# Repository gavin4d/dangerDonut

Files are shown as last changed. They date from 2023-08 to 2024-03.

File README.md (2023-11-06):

# Danger Donut

robot animation

Danger Donut is a work-in-progress 150 gram melty brain combat robot.

This repository contains:
* Code for the operations of the bot
* Code for the IR beacon modulation
* ESC configs
* Main board PCB design
* IR beacon PCB design
* POV display artwork

Links:
* [Bill of Materials](https://docs.google.com/spreadsheets/d/1dkWNEsBBoqDzMkqIhuPgsKdvJ411szMJZwjo1TRifCI/edit?usp=sharing)
* [Full Robot CAD](https://cad.onshape.com/documents/b2161876893824b000416544/w/ad922c252fa114c5bccae0f6/e/2d73a76351a9b656583123fa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)
* [IR Beacon CAD for Xbox controller](https://cad.onshape.com/documents/fe686b6ebfe56c60cbf11a52/w/a5235571450e0940f943c7f9/e/e1fc86eb24f972fd453b77be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)
* [Transport Box CAD](https://cad.onshape.com/documents/9698310442d8aade0d12c8ac/w/1dfdf825a6ce81e21ee8f0cf/e/f9df83b772e96680fdb5acf9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)

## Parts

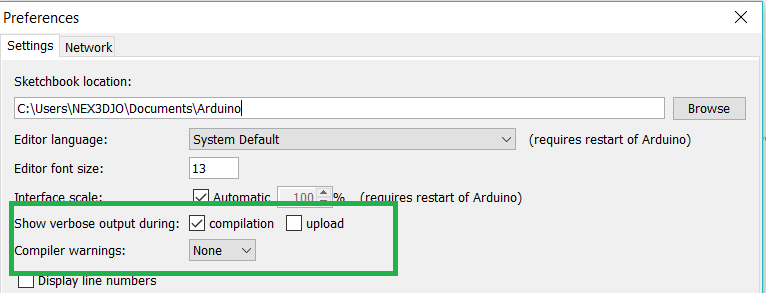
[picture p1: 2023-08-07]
components/arduino/docs/source/_static/ota_esp32_verbose.png

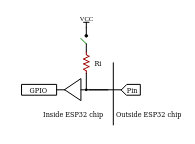
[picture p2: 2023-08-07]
components/arduino/docs/source/_static/gpio_pullup.png

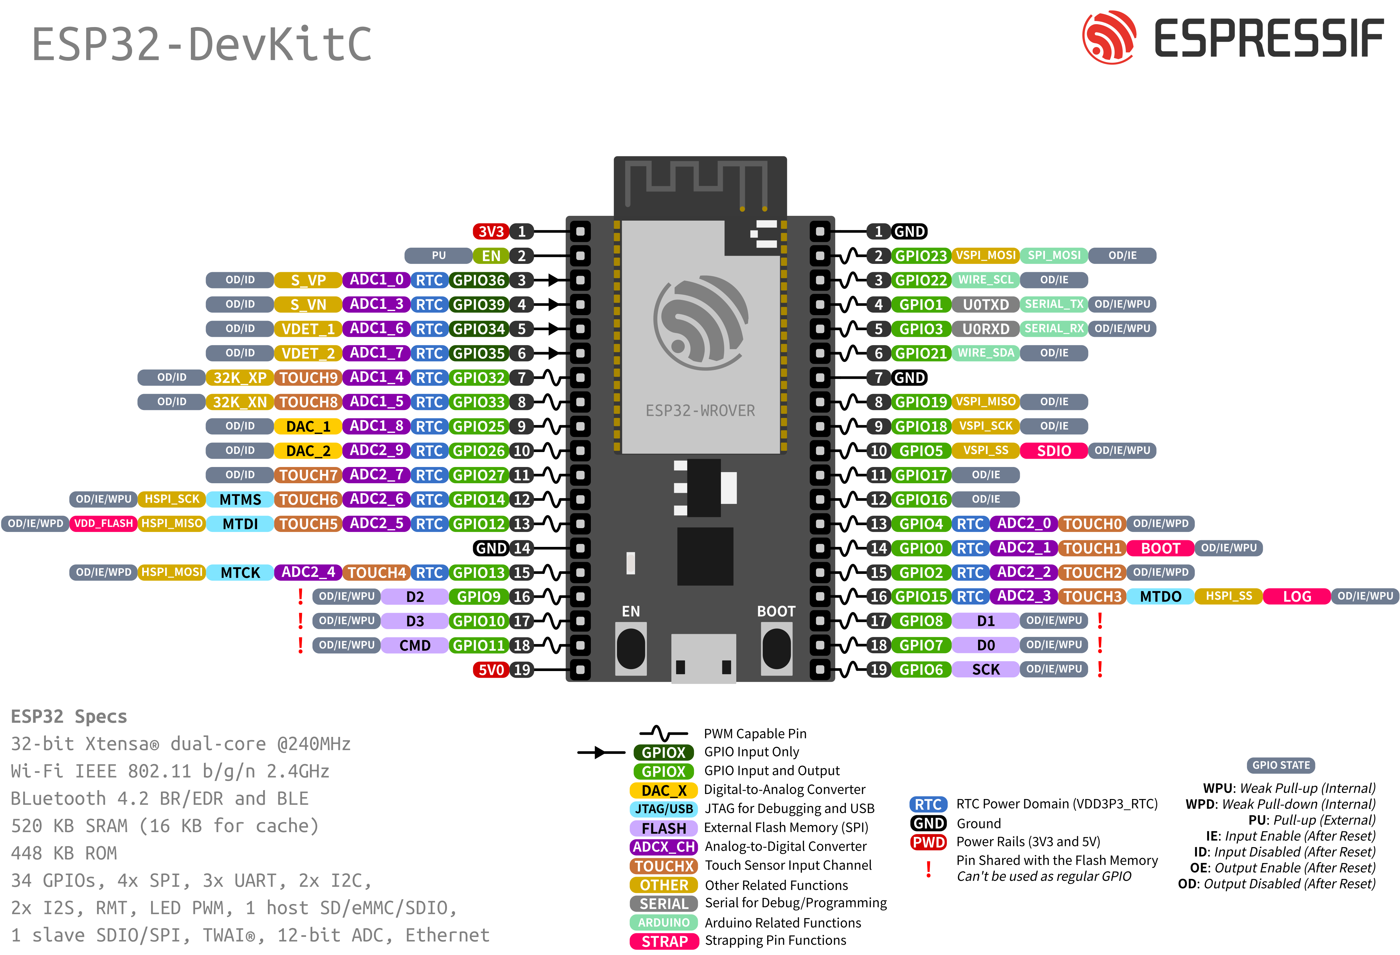
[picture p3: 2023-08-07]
components/arduino/docs/source/_static/esp32_devkitC_pinlayout.png

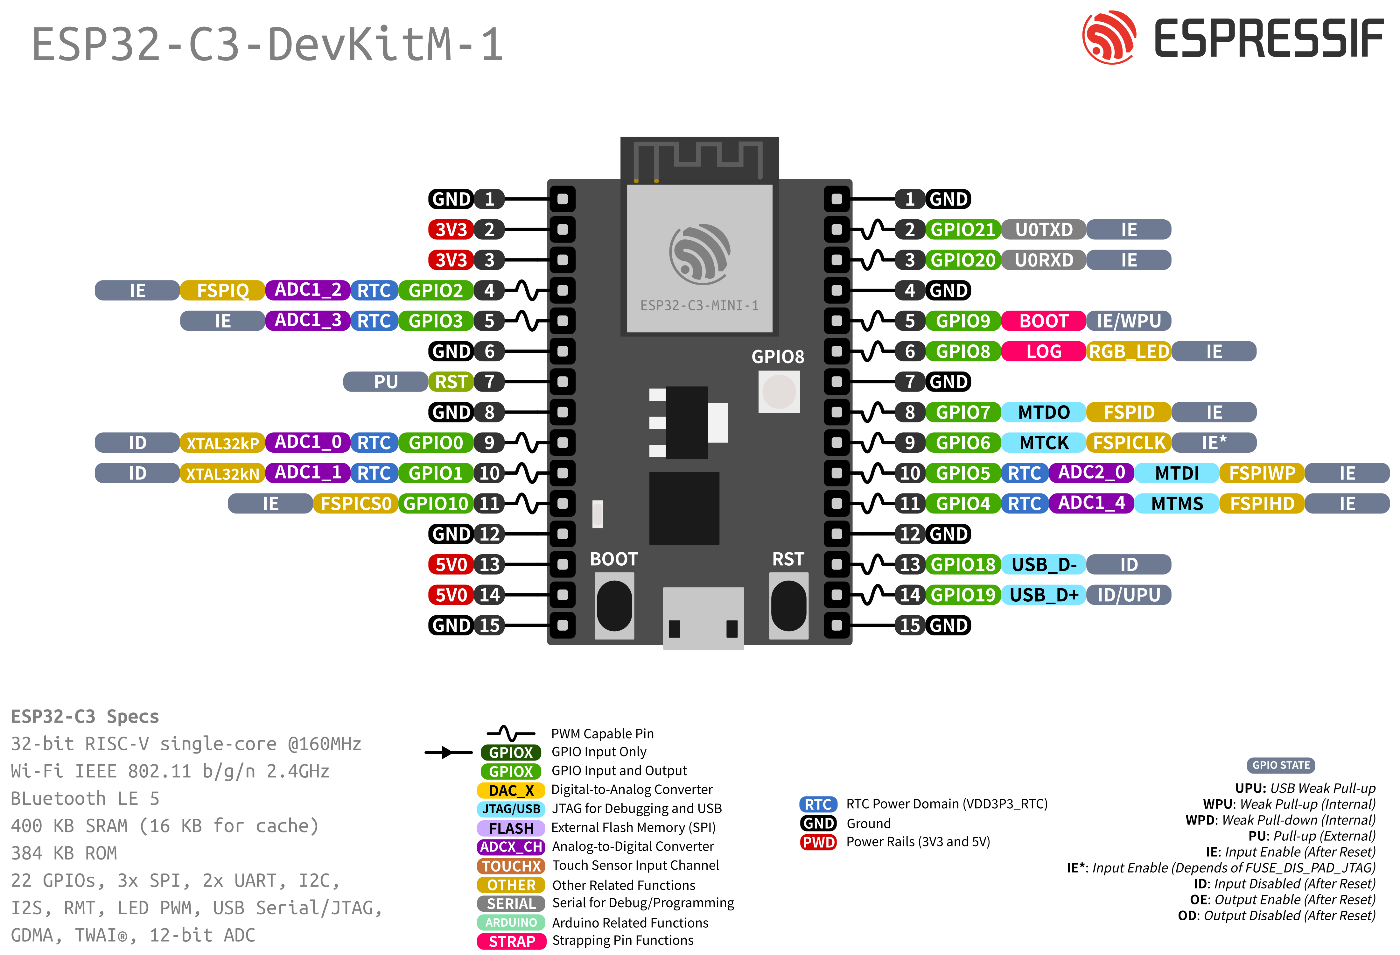
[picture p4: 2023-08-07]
components/arduino/docs/source/_static/esp32-c3_devkitM-1_pinlayout.png

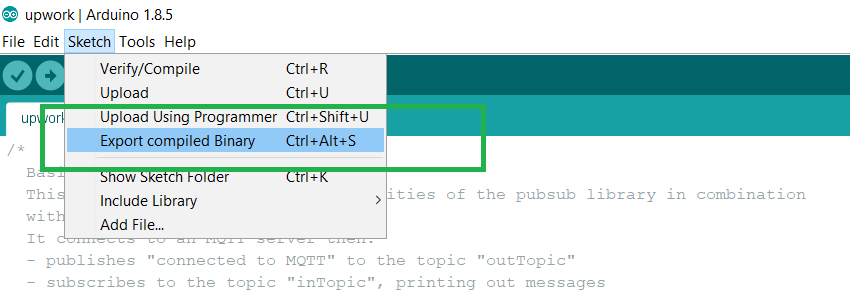
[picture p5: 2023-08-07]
components/arduino/docs/source/_static/ota_export_to_binary.png

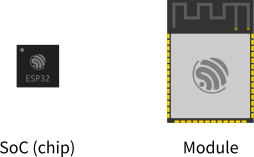
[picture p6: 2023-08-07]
components/arduino/docs/source/_static/soc-module.png

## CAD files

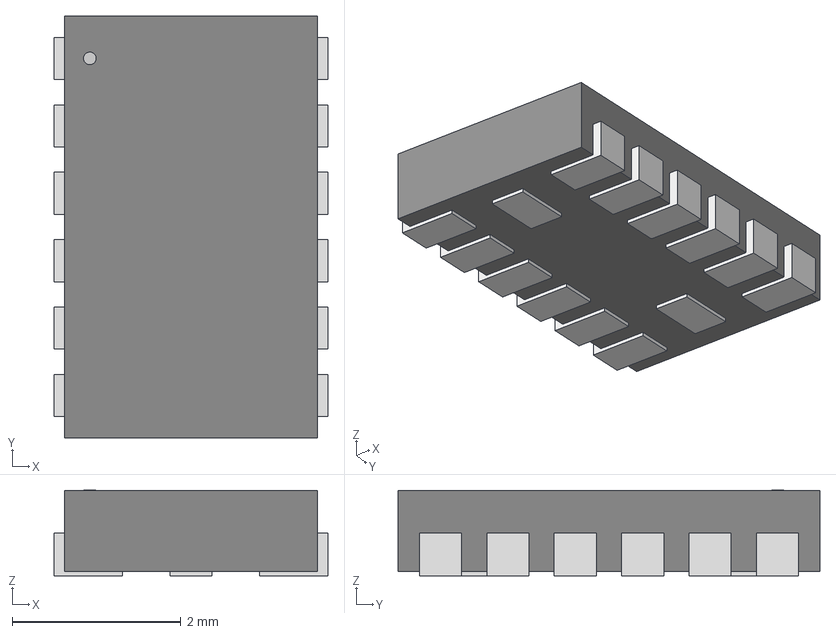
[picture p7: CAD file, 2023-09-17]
PCB/MainBoard/partFiles/step/LGA_CC-14-1_ADI.step
3.25 x 5.00 x 1.02 mm

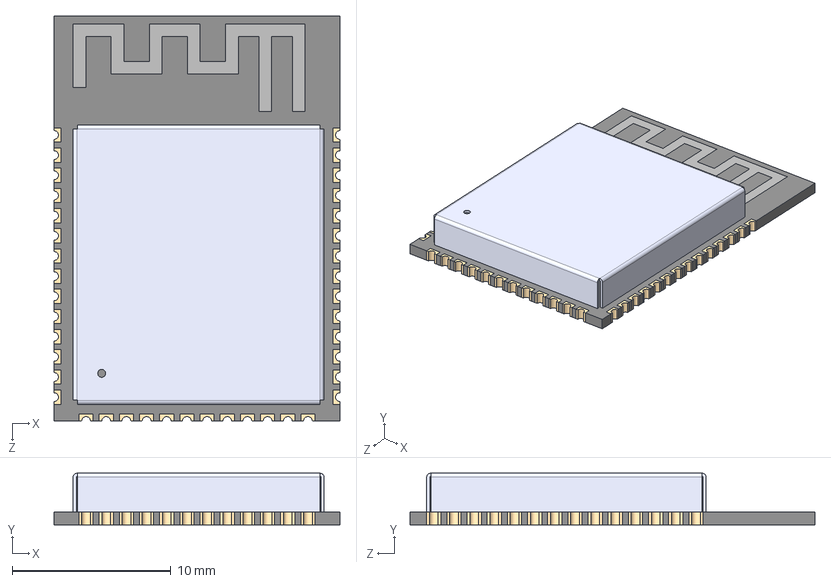
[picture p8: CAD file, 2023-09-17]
PCB/MainBoard/partFiles/step/ESP32-S3-WROOM-1-N8R2.step
18.0 x 3.25 x 25.5 mm

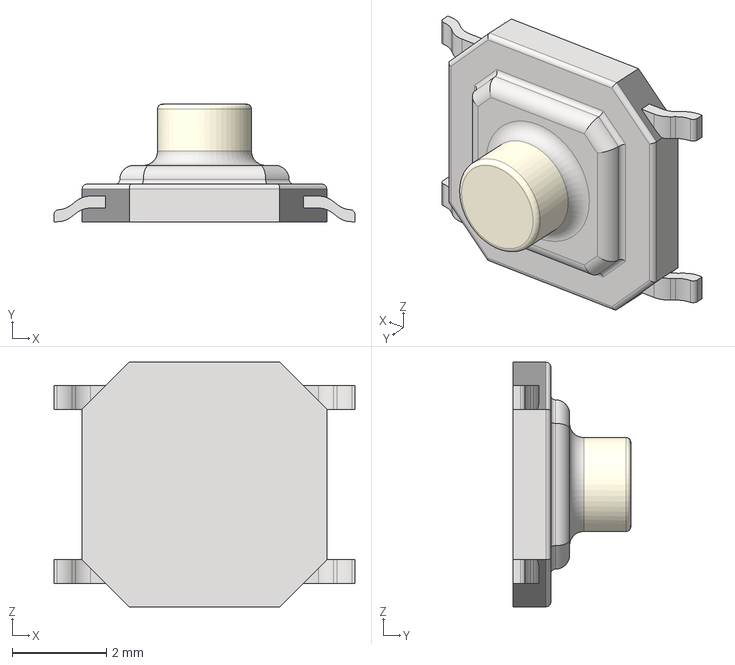
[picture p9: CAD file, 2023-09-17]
PCB/MainBoard/partFiles/step/tact_switch_2.5mm.step
6.40 x 2.50 x 5.20 mm

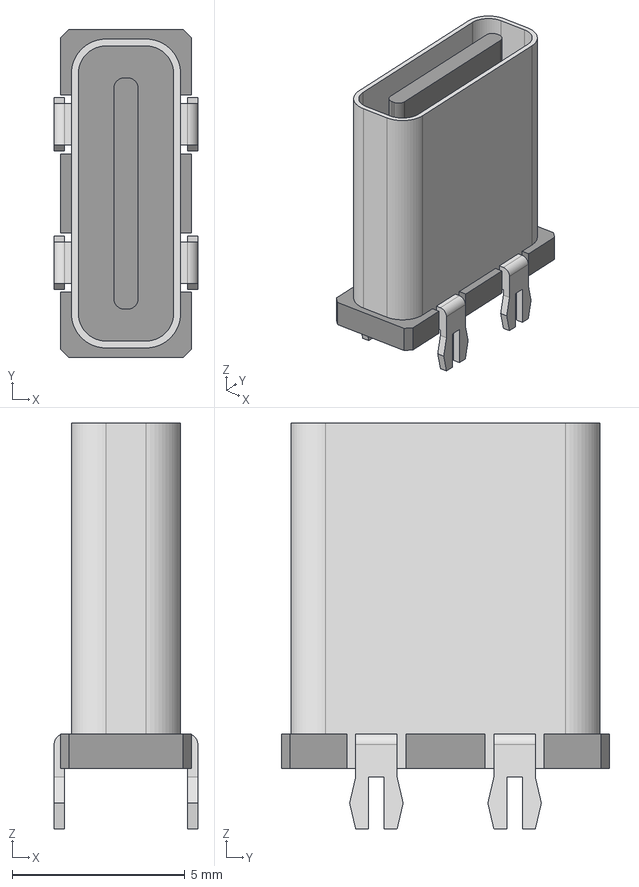
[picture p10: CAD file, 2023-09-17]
PCB/MainBoard/partFiles/step/TYPE-C_16PLC-H10.0.step
4.16 x 9.50 x 11.8 mm

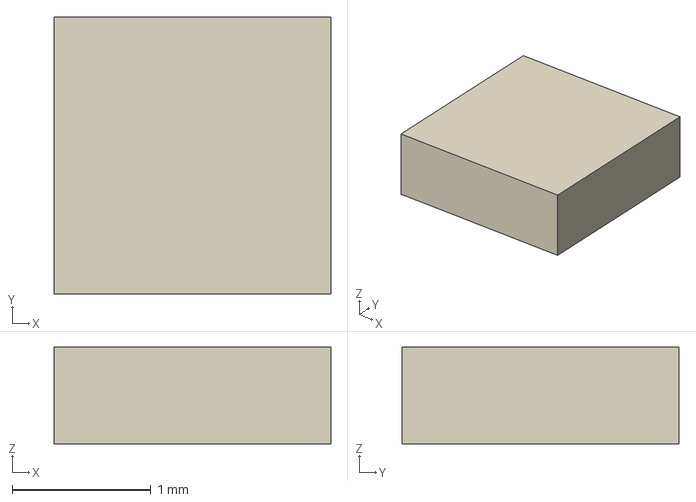
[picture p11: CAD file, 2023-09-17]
PCB/MainBoard/partFiles/step/HD107S_CAD.step
2.00 x 2.00 x 0.7 mm

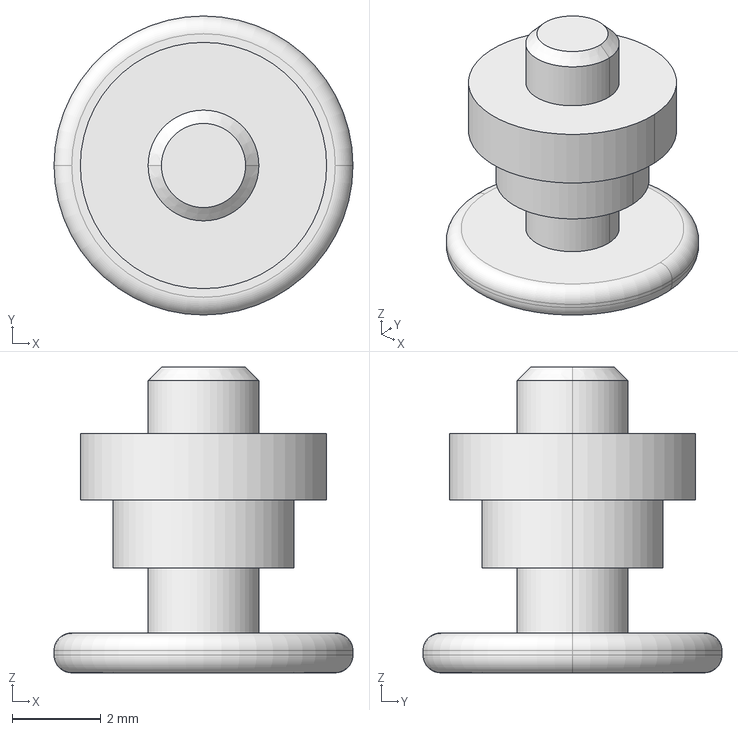
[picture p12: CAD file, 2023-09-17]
PCB/MainBoard/partFiles/step/hex bolt switch.step
6.75 x 6.75 x 6.90 mm

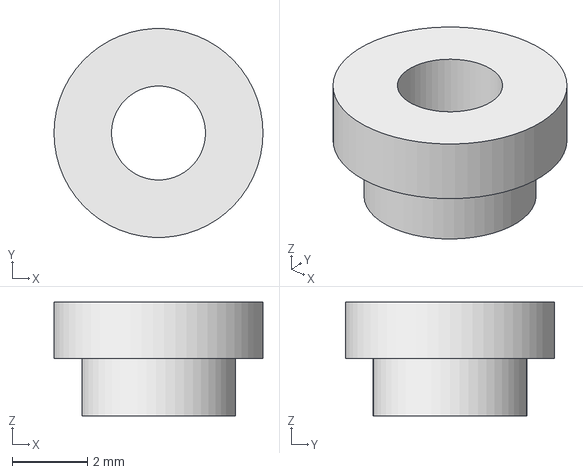
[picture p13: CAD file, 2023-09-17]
PCB/MainBoard/partFiles/step/smd nut.step
5.56 x 5.55 x 3.03 mm

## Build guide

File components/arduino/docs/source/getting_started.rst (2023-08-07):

###############
Getting Started
###############

About Arduino ESP32
-------------------

Welcome to the Arduino ESP32 support documentation! Here you will find important information on how to use the project.

First Things First
------------------

.. note::
    Before continuing, we must be clear that this project is supported by `Espressif Systems`_ and the community.
    Everyone is more than welcome to contribute back to this project.

ESP32 is a single 2.4 GHz Wi-Fi-and-Bluetooth SoC (System On a Chip) designed by `Espressif Systems`_.

ESP32 is designed for mobile, wearable electronics, and Internet-of-Things (IoT) applications. It features all the state-of-the-art characteristics 
of low-power chips, including fine-grained clock gating, multiple power modes,and dynamic power scaling. For instance, in a low-power IoT sensor 
hub application scenario, ESP32 is woken-up periodically and only when a specified condition is detected. Low-duty cycle is used to minimize the 
amount of energy that the chip expends. 

The output of the power amplifier is also adjustable, thus contributing to an optimal trade-off between communication range, data rate and 
power consumption.

The ESP32 series is available as a chip or module.

.. _supported_socs:

Supported SoC's
---------------

Here are the ESP32 series supported by the Arduino-ESP32 project:

======== ====== =========== ===================================
SoC      Stable Development Datasheet
======== ====== =========== ===================================
ESP32    Yes    Yes         `ESP32`_
ESP32-S2 Yes    Yes         `ESP32-S2`_
ESP32-C3 Yes    Yes         `ESP32-C3`_
ESP32-S3 Yes    Yes         `ESP32-S3`_
======== ====== =========== ===================================

See `Boards <boards/boards.html>`_ for more details about ESP32 development boards.

Arduino Core Reference
----------------------

This documentation is built on the ESP32 and we are not going to cover the common Arduino API. To see the Arduino reference documentation, 
please consider reading the official documentation.

Arduino Official Documentation: `Arduino Reference`_.

Supported Operating Systems
---------------------------

+-------------------+-------------------+-------------------+
|     |       |       |
+-------------------+-------------------+-------------------+
| Windows           | Linux             | macOS             |
+-------------------+-------------------+-------------------+





Supported IDEs
---------------------------

Here is the list of supported IDE for Arduino ESP32 support integration.

+-------------------+-------------------+
|     |         |
+-------------------+-------------------+
| Arduino IDE       | PlatformIO        |
+-------------------+-------------------+




See `Installing Guides <installing.html>`_ for more details on how to install the Arduino ESP32 support.

Support
-------

This is an open project and it's supported by the community. Fell free to ask for help in one of the community channels.

Community
---------

The Arduino community is huge! You can find a lot of useful content on the Internet.
Here are some community channels where you may find information and ask for some help, if needed.

- `ESP32 Forum`_: Official Espressif Forum.
- `ESP32 Forum - Arduino`_: Official Espressif Forum for Arduino related discussions.
- `ESP32 Forum - Hardware`_: Official Espressif Forum for Hardware related discussions.
- `Gitter`_
- `Espressif MCUs (Discord)`_
- `ESP32 on Reddit`_

Issues Reporting
----------------

Before opening a new issue, please read this: 

Be sure to search for a similar reported issue. This avoids duplicating or creating noise in the GitHub Issues reporting.
We also have the troubleshooting guide to save your time on the most common issues reported by users.

For more details about creating new Issue, see the `Issue Template <https://github.com/espressif/arduino-esp32/blob/master/.github/ISSUE_TEMPLATE/Issue-report.yml>`_.

If you have any new idea, see the `Feature request Template <https://github.com/espressif/arduino-esp32/blob/master/.github/ISSUE_TEMPLATE/Feature-request.yml>`_.

First Steps
-----------

Here are the first steps to get the Arduino ESP32 support running.

To install Arduino-ESP32, please see the dedicated section on the Installation guide. We recommend you install it using the boards manager.

.. toctree::
    :maxdepth: 2
    
    How to Install <installing>
    Development Boards <boards/boards>

Examples
--------

After installing the toolchain into your environment, you will be able to see all the dedicated examples for the ESP32. These examples are located
in the examples menu or inside each library folder.

    https://github.com/espressif/arduino-esp32/tree/master/libraries

There is also a `list of examples <https://techtutorialsx.com/category/esp32/>`_ managed outside of Espressif, so check them out.

.. include:: common/datasheet.inc

Resources
---------

.. _Espressif Systems: https://www.espressif.com 
.. _Espressif Product Selector: https://products.espressif.com/
.. _Arduino.cc: https://www.arduino.cc/en/Main/Software
.. _Arduino Reference: https://www.arduino.cc/reference/en/
.. _ESP32 Forum: https://esp32.com
.. _ESP32 Forum - Arduino: https://esp32.com/viewforum.php?f=19
.. _ESP32 Forum - Hardware: https://esp32.com/viewforum.php?f=12
.. _Gitter: https://gitter.im/espressif/arduino-esp32
.. _Adafruit (Discord): https://discord.gg/adafruit
.. _Espressif MCUs (Discord): https://discord.gg/nKxMTnkD
.. _ESP32 on Reddit: https://www.reddit.com/r/esp32

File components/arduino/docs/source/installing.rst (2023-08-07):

##########
Installing
##########

This guide will show how to install the Arduino-ESP32 support.

Before Installing
-----------------

We recommend you install the support using your favorite IDE, but other options are available depending on your operating system. 
To install Arduino-ESP32 support, you can use one of the following options.

Installing using Arduino IDE
----------------------------



This is the way to install Arduino-ESP32 directly from the Arduino IDE.

.. note::
   For overview of SoC's support, take a look on `Supported Soc's table <https://docs.espressif.com/projects/arduino-esp32/en/latest/getting_started.html#supported-soc-s>`_ where you can find if the particular chip is under stable or development release.

- Stable release link::

   https://espressif.github.io/arduino-esp32/package_esp32_index.json

- Development release link::

   https://espressif.github.io/arduino-esp32/package_esp32_dev_index.json

.. note::
   Starting with the Arduino IDE version 1.6.4, Arduino allows installation of third-party platform 
   packages using Boards Manager. We have packages available for Windows, macOS, and Linux.

To start the installation process using the Boards Managaer, follow these steps:

-  Install the current upstream Arduino IDE at the 1.8 level or later. The current version is at the `arduino.cc`_ website.

-  Start Arduino and open the Preferences window.



-  Enter one of the release links above into *Additional Board Manager URLs* field. You can add multiple URLs, separating them with commas.



-  Open Boards Manager from Tools > Board menu and install *esp32* platform (and do not forget to select your ESP32 board from Tools > Board menu after installation).



- Restart Arduino IDE.

Installing using PlatformIO
---------------------------



PlatformIO is a professional collaborative platform for embedded development. It has out-of-the-box support for ESP32 SoCs and allows working with Arduino ESP32 as well as ESP-IDF from Espressif without changing your development environment. PlatformIO includes lots of instruments for the most common development tasks such as debugging, unit testing, and static code analysis.

A detailed overview of the PlatformIO ecosystem and its philosophy can be found in `the official documentation <https://docs.platformio.org/en/latest/core/index.html>`_.

PlatformIO can be used in two flavors:

- `PlatformIO IDE <https://platformio.org/platformio-ide>`_ is a toolset for embedded C/C++ development available on Windows, macOS and Linux platforms

- `PlatformIO Core (CLI) <https://docs.platformio.org/en/latest/core/index.html>`_ is a command-line tool that consists of a multi-platform build system, platform and library managers and other integration components. It can be used with a variety of code development environments and allows integration with cloud platforms and web services

To install PlatformIO, you can follow this Getting Started, provided at `docs.platformio.org`_.

Using the stable code
*********************

.. note::
   A detailed overview of supported development boards, examples and frameworks can be found on `the official Espressif32 dev-platform page <https://registry.platformio.org/platforms/platformio/espressif32>`_ in the PlatformIO Registry.

The most reliable and easiest way to get started is to use the latest stable version of the ESP32 development platform that passed all tests/verifications and can be used in production.

Create a new project and select one of the available boards. You can change after by changing the `platformio.ini <https://docs.platformio.org/en/latest/projectconf/index.html>`_ file.

- For ESP32

.. code-block:: bash

   [env:esp32dev]
   platform = espressif32
   board = esp32dev
   framework = arduino

- For ESP32-S2 (ESP32-S2-Saola-1 board)

.. code-block:: bash

   [env:esp32-s2-saola-1]
   platform = espressif32
   board = esp32-s2-saola-1
   framework = arduino

- For ESP32-C3 (ESP32-C3-DevKitM-1 board)

.. code-block:: bash

   [env:esp32-c3-devkitm-1]
   platform = espressif32
   board = esp32-c3-devkitm-1
   framework = arduino

How to update to the latest code
********************************

To test the latest Arduino ESP32, you need to change your project *platformio.ini* accordingly.
The following configuration uses the upstream version of the Espressif development platform and the latest Arduino core directly from the Espressif GitHub repository:

.. code-block:: bash

   [env:esp32-c3-devkitm-1]
   platform = https://github.com/platformio/platform-espressif32.git
   board = esp32-c3-devkitm-1
   framework = arduino
   platform_packages =
       framework-arduinoespressif32 @ https://github.com/espressif/arduino-esp32#master

To get more information about PlatformIO, see the following links:

- `PlatformIO Core (CLI) <https://docs.platformio.org/en/latest/core/index.html>`_

- `PlatformIO Home <https://docs.platformio.org/en/latest/home/index.html>`_

- `Tutorials and Examples <https://docs.platformio.org/en/latest/tutorials/index.html>`_

- `Library Management <https://docs.platformio.org/en/latest/librarymanager/index.html>`_

Windows (manual installation)
-----------------------------

.. warning:: Arduino ESP32 core v2.x.x cannot be used on Windows 8.x x86 (32 bits), Windows 7 or earlier. The Windows 32 bits OS is no longer supported by this toolchain.

   The Arduino ESP32 v1.0.6 still works on WIN32. You might want to install python 3.8.x because it is the latest release supported by Windows 7.

Steps to install Arduino ESP32 support on Windows:

**Step 1**

1. Download and install the latest Arduino IDE ``Windows Installer`` from [arduino.cc](https://www.arduino.cc/en/Main/Software)
2. Download and install Git from [git-scm.com](https://git-scm.com/download/win)
3. Start ``Git GUI`` and do the following steps:

- Select ``Clone Existing Repository``



- Select source and destination
   - Sketchbook Directory: Usually ``C:/Users/[YOUR_USER_NAME]/Documents/Arduino`` and is listed underneath the "Sketchbook location" in Arduino preferences.
   - Source Location: ``https://github.com/espressif/arduino-esp32.git``
   - Target Directory: ``[ARDUINO_SKETCHBOOK_DIR]/hardware/espressif/esp32``
   - Click ``Clone`` to start cloning the repository

**Step 2**



**Step 3**



- open a `Git Bash` session pointing to ``[ARDUINO_SKETCHBOOK_DIR]/hardware/espressif/esp32`` and execute ```git submodule update --init --recursive``` 
- Open ``[ARDUINO_SKETCHBOOK_DIR]/hardware/espressif/esp32/tools`` and double-click ``get.exe``

**Step 4**



- When ```get.exe``` finishes, you should see the following files in the directory

**Step 5**



1. Plug your ESP32 board and wait for the drivers to install (or install manually any that might be required)
2. Start Arduino IDE
3. Select your board in ``Tools > Board`` menu
4. Select the COM port that the board is attached to
5. Compile and upload (You might need to hold the boot button while uploading)



How to update to the latest code
********************************

1. Start ``Git GUI`` and you should see the repository under ``Open Recent Repository``. Click on it!



1. From menu ``Remote`` select ``Fetch from`` > ``origin``



1. Wait for git to pull any changes and close ``Git GUI``
2. Open ``[ARDUINO_SKETCHBOOK_DIR]/hardware/espressif/esp32/tools`` and double-click ``get.exe``



Linux
-----



Debian/Ubuntu
*************

- Install latest Arduino IDE from `arduino.cc`_.

- Open Terminal and execute the following command (copy -> paste and hit enter):

.. code-block:: bash

   sudo usermod -a -G dialout $USER && \
   sudo apt-get install git && \
   wget https://bootstrap.pypa.io/get-pip.py && \
   sudo python3 get-pip.py && \
   sudo pip3 install pyserial && \
   mkdir -p ~/Arduino/hardware/espressif && \
   cd ~/Arduino/hardware/espressif && \
   git clone https://github.com/espressif/arduino-esp32.git esp32 && \
   cd esp32/tools && \
   python3 get.py

- Restart Arduino IDE.

- If you have Arduino installed to ~/, modify the installation as follows, beginning at `mkdir -p ~/Arduino/hardware`:

.. code-block:: bash

   cd ~/Arduino/hardware
   mkdir -p espressif && \
   cd espressif && \
   git clone https://github.com/espressif/arduino-esp32.git esp32 && \
   cd esp32/tools && \
   python3 get.py

Fedora
******

- Install the latest Arduino IDE from `arduino.cc`_.

.. note::
   Command ``$ sudo dnf -y install arduino`` will most likely install an older release.

- Open Terminal and execute the following command (copy -> paste and hit enter):

.. code-block:: bash

   sudo usermod -a -G dialout $USER && \
   sudo dnf install git python3-pip python3-pyserial && \
   mkdir -p ~/Arduino/hardware/espressif && \
   cd ~/Arduino/hardware/espressif && \
   git clone https://github.com/espressif/arduino-esp32.git esp32 && \
   cd esp32/tools && \
   python get.py

- Restart Arduino IDE.

openSUSE
********

- Install the latest Arduino IDE from `arduino.cc`_.

- Open Terminal and execute the following command (copy -> paste and hit enter):

.. code-block:: bash

   sudo usermod -a -G dialout $USER && \
   if [ `python --version 2>&1 | grep '2.7' | wc -l` = "1" ]; then \
   sudo zypper install git python-pip python-pyserial; \
   else \
   sudo zypper install git python3-pip python3-pyserial; \
   fi && \
   mkdir -p ~/Arduino/hardware/espressif && \
   cd ~/Arduino/hardware/espressif && \
   git clone https://github.com/espressif/arduino-esp32.git esp32 && \
   cd esp32/tools && \
   python get.py

- Restart Arduino IDE.

macOS
-----

- Install the latest Arduino IDE from `arduino.cc`_.

- Open Terminal and execute the following command (copy -> paste and hit enter):

.. code-block:: bash

   mkdir -p ~/Documents/Arduino/hardware/espressif && \
   cd ~/Documents/Arduino/hardware/espressif && \
   git clone https://github.com/espressif/arduino-esp32.git esp32 && \
   cd esp32/tools && \
   python get.py 

Where ``~/Documents/Arduino`` represents your sketch book location as per "Arduino" > "Preferences" > "Sketchbook location" (in the IDE once started). Adjust the command above accordingly.

- If you get the error below, install through the command line dev tools with `xcode-select --install` and try the command above again:

.. code-block:: bash

   xcrun: error: invalid active developer path (/Library/Developer/CommandLineTools), missing xcrun at: /Library/Developer/CommandLineTools/usr/bin/xcrun

- Run the command:

.. code-block:: bash

   xcode-select --install

- Try ``python3`` instead of ``python`` if you get the error: ``IOError: [Errno socket error] [SSL: TLSV1_ALERT_PROTOCOL_VERSION] tlsv1 alert protocol version (_ssl.c:590)`` when running ``python get.py``

- If you get the following error when running ``python get.py`` urllib.error.URLError: <urlopen error SSL: CERTIFICATE_VERIFY_FAILED, go to Macintosh HD > Applications > Python3.6 folder (or any other python version), and run the following scripts: Install Certificates.command and Update Shell Profile.command

- Restart Arduino IDE.

.. _Arduino.cc: https://www.arduino.cc/en/Main/Software
.. _docs.platformio.org: https://docs.platformio.org/en/latest/integration/ide/pioide.html

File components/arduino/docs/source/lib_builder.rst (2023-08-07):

###############
Library Builder
###############

About
-----

Espressif provides a `tool <https://github.com/espressif/esp32-arduino-lib-builder>`_ to simplify building your own compiled libraries for use in Arduino IDE (or your favorite IDE).

This tool can be used to change the project or a specific configuration according to your needs.

Installing
----------

To install the Library Builder into your environment, please, follow the instructions below.

- Clone the ESP32 Arduino lib builder:

.. code-block:: bash

    git clone https://github.com/espressif/esp32-arduino-lib-builder

- Go to the ``esp32-arduino-lib-builder`` folder:

.. code-block:: bash

    cd esp32-arduino-lib-builder

- Build:

.. code-block:: bash

    ./build.sh

If everything works, you may see the following message: ``Successfully created esp32 image.``

Dependencies
************

To build the library you will need to install some dependencies. Maybe you already have installed it, but it is a good idea to check before building.

- Install all dependencies (**Ubuntu**):

.. code-block:: bash

    sudo apt-get install git wget curl libssl-dev libncurses-dev flex bison gperf cmake ninja-build ccache jq

- Install Python and upgrade pip:

.. code-block:: bash

    sudo apt-get install python3
    sudo pip install --upgrade pip

- Install all required packages:

.. code-block:: bash

    pip install --user setuptools pyserial click cryptography future pyparsing pyelftools

Building
--------

If you have all the dependencies met, it is time to build the libraries.

To build using the default configuration:

.. code-block:: bash

    ./build.sh

Custom Build
************

There are some options to help you create custom libraries. You can use the following options:

Usage
^^^^^

.. code-block:: bash

    build.sh [-s] [-A arduino_branch] [-I idf_branch] [-i idf_commit] [-c path] [-t <target>] [-b <build|menuconfig|idf_libs|copy_bootloader|mem_variant>] [config ...]

Skip Install/Update
^^^^^^^^^^^^^^^^^^^

Skip installing/updating of ESP-IDF and all components

.. code-block:: bash

    ./build.sh -s

This option can be used if you already have the ESP-IDF and all components already in your environment.

Set Arduino-ESP32 Branch
^^^^^^^^^^^^^^^^^^^^^^^^

Set which branch of arduino-esp32 to be used for compilation

.. code-block:: bash

    ./build.sh -A <arduino_branch>

Set ESP-IDF Branch
^^^^^^^^^^^^^^^^^^

Set which branch of ESP-IDF is to be used for compilation

.. code-block:: bash

    ./build.sh -I <idf_branch>

Set the ESP-IDF Commit
^^^^^^^^^^^^^^^^^^^^^^

Set which commit of ESP-IDF to be used for compilation

.. code-block:: bash

    ./build.sh -i <idf_commit>

Deploy
^^^^^^

Deploy the build to github arduino-esp32

.. code-block:: bash

    ./build.sh -d

Set the Arduino-ESP32 Destination Folder
^^^^^^^^^^^^^^^^^^^^^^^^^^^^^^^^^^^^^^^^

Set the arduino-esp32 folder to copy the result to. ex. '$HOME/Arduino/hardware/espressif/esp32'

.. code-block:: bash

    ./build.sh -c <path>

This function is used to copy the compiled libraries to the Arduino folder.

Set the Target
^^^^^^^^^^^^^^

Set the build target(chip). ex. 'esp32s3'

.. code-block:: bash

    ./build.sh -t <target>

This build command will build for the ESP32-S3 target. You can specify other targets.

* esp32
* esp32s2
* esp32c3
* esp32s3

Set Build Type
^^^^^^^^^^^^^^

Set the build type. ex. 'build' to build the project and prepare for uploading to a board.

.. note:: This command depends on the ``-t`` argument.

.. code-block:: bash

    ./build.sh -t esp32 -b <build|menuconfig|idf_libs|copy_bootloader|mem_variant>

Additional Configuration
^^^^^^^^^^^^^^^^^^^^^^^^

Specify additional configs to be applied. ex. 'qio 80m' to compile for QIO Flash@80MHz. Requires -b

.. note:: This command requires the ``-b`` to work properly.

.. code-block:: bash

    ./build.sh -t esp32 -b idf_libs qio 80m

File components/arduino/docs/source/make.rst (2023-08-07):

==============
makeEspArduino
==============

The `makeEspArduino <https://github.com/plerup/makeEspArduino>`_ is a generic makefile for any ESP8266/ESP32 Arduino project. 
Using it instead of the Arduino IDE makes it easier to do automated and production builds.

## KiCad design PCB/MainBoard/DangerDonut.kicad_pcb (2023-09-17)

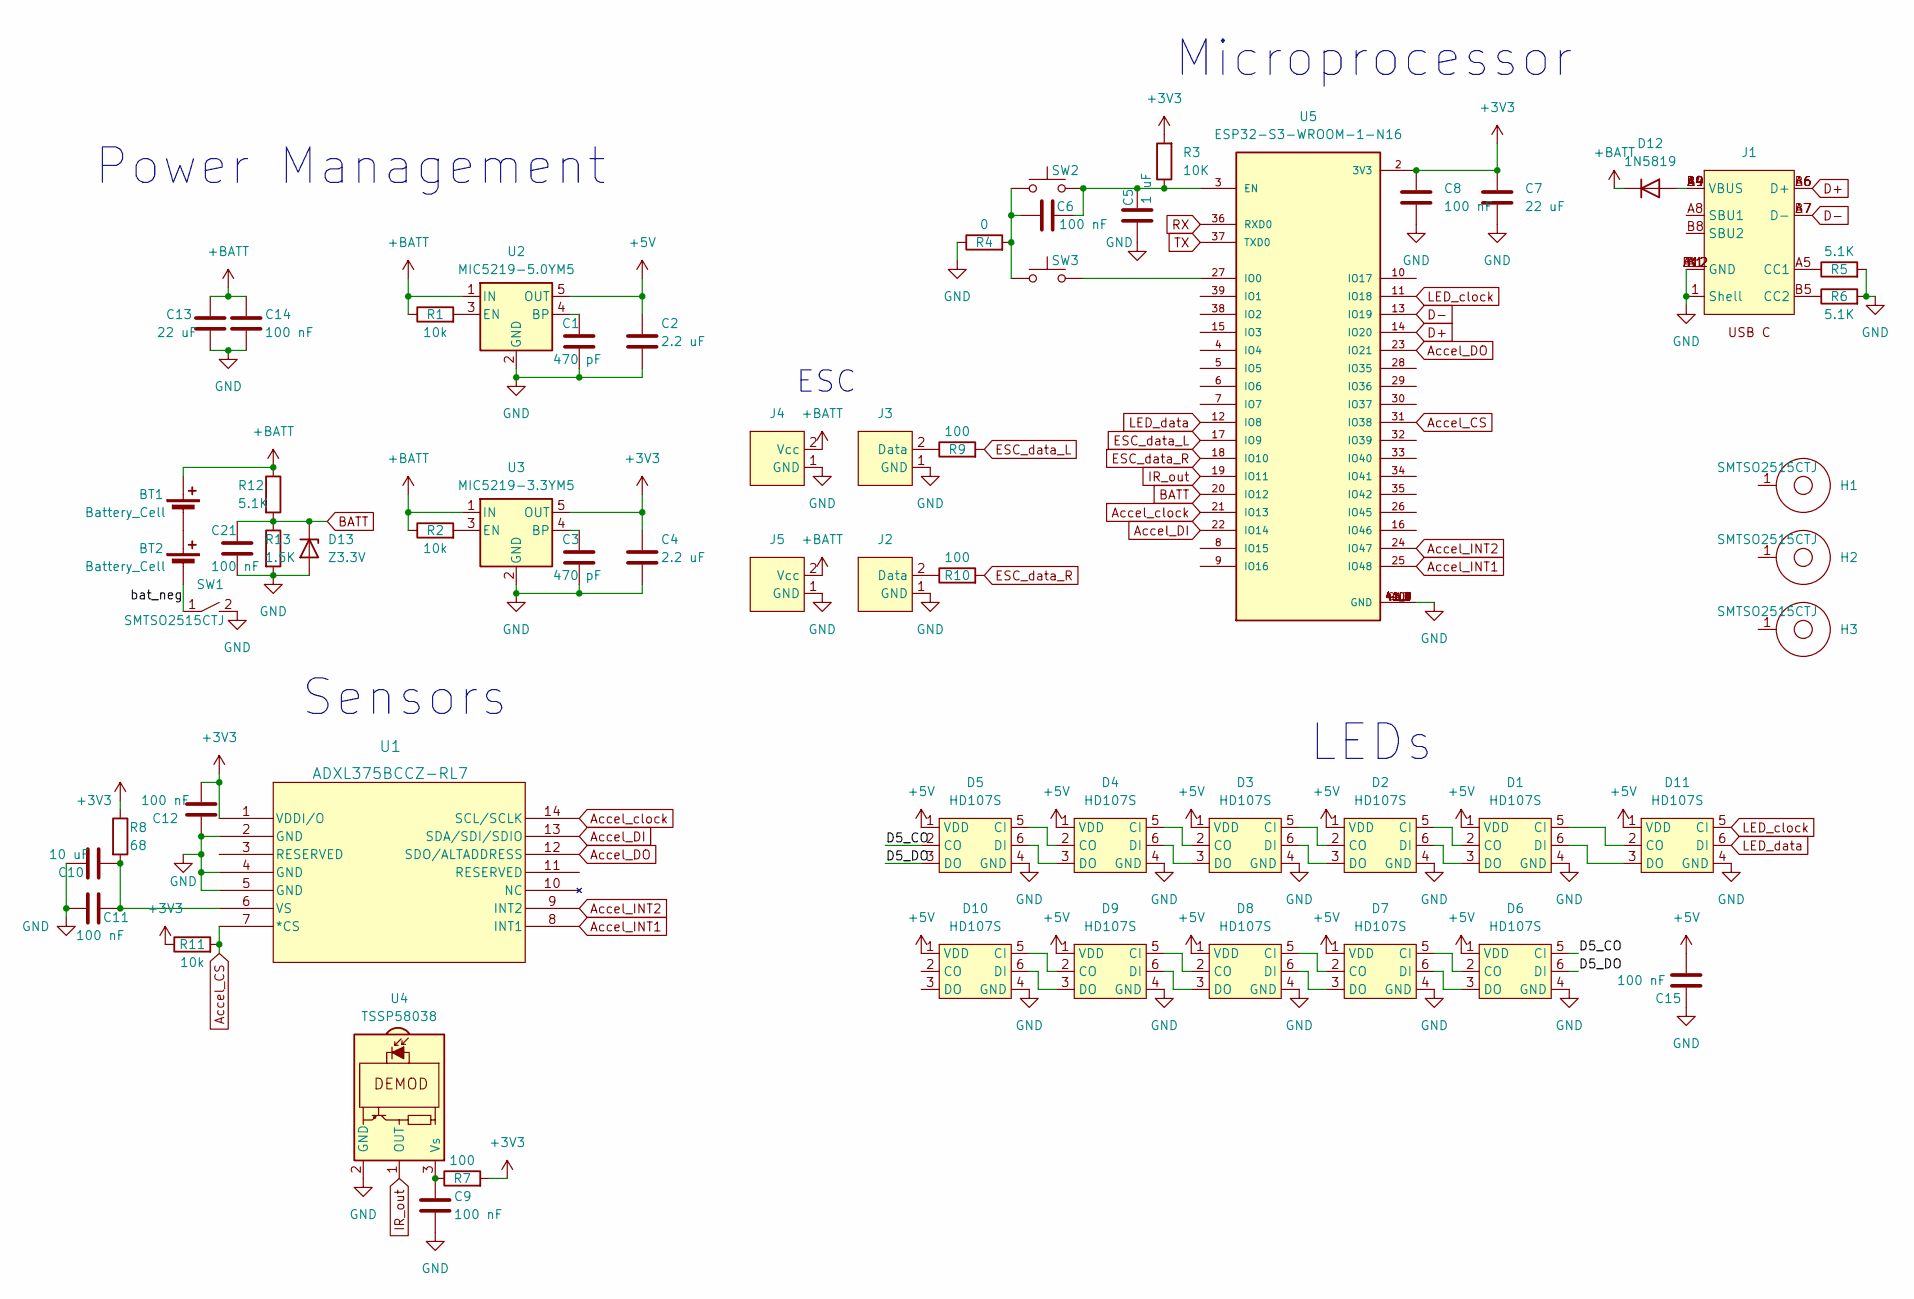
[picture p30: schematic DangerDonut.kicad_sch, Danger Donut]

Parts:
BT1, BT2: Battery_Cell; Battery_Solder_Point
C1, C3: 470 pF; C_0603_1608Metric
C2, C4: 2.2 uF; C_0603_1608Metric
C5: 1 uF; C_0603_1608Metric
C6, C8, C9, C11, C12, C14, C15, C21: 100 nF; C_0603_1608Metric
C7, C13: 22 uF; C_1206_3216Metric
C10: 10 uF; C_0805_2012Metric
D1, D2, D3, D4, D5, D6, D7, D8, D9, D10, D11: HD107S
D12: 1N5819; D_SOD-323
D13: Z3.3V; D_MiniMELF; Part ZMM3V3-M
H1, H2, H3: SMTSO2515CTJ; SMTSO2515
J1: TYPE_C_16PLC_H100
J2, J3: ESC_XSD7A_Data
J4, J5: ESC_XSD7A_Power
R1, R2, R11: 10k; R_0603_1608Metric
R3: 10K; R_0603_1608Metric
R4: 0; R_0603_1608Metric; Part 0603WAF0000T5E
R5, R6, R12: 5.1K; R_0603_1608Metric
R7, R9, R10: 100; R_0603_1608Metric
R8: 68; R_0603_1608Metric
R13: 1.5K; R_0603_1608Metric
SW1: SMTSO2515CTJ; SMTSO2515_SW
SW2, SW3: SW_Push; SW_Push_1P1T_XKB_TS-1187A
U1: ADXL375BCCZ-RL7; LGA_CC-14-1_ADI-M
U2: MIC5219-5.0YM5; SOT-23-5
U3: MIC5219-3.3YM5; SOT-23-5
U4: TSSP58038; Vishay_MINICAST-3Pin
U5: ESP32-S3-WROOM-1-N16; XCVR_ESP32-S3-WROOM-1-N16; PARTREV v1.0; DigiKey_Part_Number 1965-ESP32-S3-WROOM-1-N16-ND

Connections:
+3V3: C4.1, C7.1, C8.1, C12.2, R3.2, R7.2, R8.1, R11.1, U1.1 (VDDI/O), U3.5 (OUT), U5.2 (3V3); also elsewhere on the board
+5V: C2.1, C15.2, D1.1 (VDD), D2.1 (VDD), D3.1 (VDD), D4.1 (VDD), D5.1 (VDD), D6.1 (VDD), D7.1 (VDD), D8.1 (VDD), D9.1 (VDD), D10.1 (VDD), D11.1 (VDD), U2.5 (OUT); also elsewhere on the board
+BATT: BT1.1 (+), C13.1, C14.1, D12.1 (K), J4.2 (Vcc), J5.2 (Vcc), R1.1, R2.1, R12.1, U2.1 (IN), U3.1 (IN)
/D5_CO: D5.2 (CO), D6.5 (CI)
/D5_DO: D5.3 (DO), D6.6 (DI)
/bat_neg: BT2.2 (-), SW1.1
Accel_CS: R11.2, U1.7 (*CS), U5.31 (IO38)
Accel_DI: U1.13 (SDA/SDI/SDIO), U5.22 (IO14)
Accel_DO: U1.12 (SDO/ALTADDRESS), U5.23 (IO21)
Accel_INT1: U1.8 (INT1), U5.25 (IO48)
Accel_INT2: U1.9 (INT2), U5.24 (IO47)
Accel_clock: U1.14 (SCL/SCLK), U5.21 (IO13)
BATT: C21.1, D13.1 (K), R12.2, R13.1, U5.20 (IO12)
D+: J1.A6 (D+), J1.B6 (D+), U5.14 (IO20)
D-: J1.A7 (D-), J1.B7 (D-), U5.13 (IO19)
ESC_data_L: R9.2, U5.17 (IO9)
ESC_data_R: R10.2, U5.18 (IO10)
GND: C1.2, C2.2, C3.2, C4.2, C5.2, C7.2, C8.2, C9.2, C10.2, C11.2, C12.1, C13.2, C14.2, C15.1, C21.2, D1.4 (GND), D2.4 (GND), D3.4 (GND), D4.4 (GND), D5.4 (GND), D6.4 (GND), D7.4 (GND), D8.4 (GND), D9.4 (GND), D10.4 (GND), D11.4 (GND), D13.2 (A), J1.1 (Shell), J1.A1 (GND), J1.A12 (GND), J1.B1 (GND), J1.B12 (GND), J2.1 (GND), J3.1 (GND), J4.1 (GND), J5.1 (GND), R4.1, R5.2, R6.2, R13.2, SW1.2, U1.2 (GND), U1.4 (GND), U1.5 (GND), U2.2 (GND), U3.2 (GND), U4.2 (GND), U5.1 (GND), U5.40 (GND), U5.41_1 (GND), U5.41_2 (GND), U5.41_3 (GND), U5.41_4 (GND), U5.41_5 (GND), U5.41_6 (GND), U5.41_7 (GND), U5.41_8 (GND), U5.41_9 (GND), U5.GND; also elsewhere on the board
IR_out: U4.1 (OUT), U5.19 (IO11)
LED_clock: D11.5 (CI), U5.11 (IO18)
LED_data: D11.6 (DI), U5.12 (IO8)
unnamed: BT1.2 (-), BT2.1 (+)
unnamed: C6.1, R4.2, SW2.1, SW3.1
unnamed: D1.5 (CI), D11.2 (CO)
unnamed: D1.2 (CO), D2.5 (CI)
unnamed: D1.6 (DI), D11.3 (DO)
unnamed: D1.3 (DO), D2.6 (DI)
unnamed: D2.2 (CO), D3.5 (CI)
unnamed: D2.3 (DO), D3.6 (DI)
unnamed: D3.2 (CO), D4.5 (CI)
unnamed: D3.3 (DO), D4.6 (DI)
unnamed: D4.2 (CO), D5.5 (CI)
unnamed: D4.3 (DO), D5.6 (DI)
unnamed: D6.2 (CO), D7.5 (CI)
unnamed: D6.3 (DO), D7.6 (DI)
unnamed: D7.2 (CO), D8.5 (CI)
unnamed: D7.3 (DO), D8.6 (DI)
unnamed: D8.2 (CO), D9.5 (CI)
unnamed: D8.3 (DO), D9.6 (DI)
unnamed: D9.2 (CO), D10.5 (CI)
unnamed: D9.3 (DO), D10.6 (DI)
unnamed: D12.2 (A), J1.A4 (VBUS), J1.A9 (VBUS), J1.B4 (VBUS), J1.B9 (VBUS)
unnamed: J1.A5 (CC1), R5.1
unnamed: J1.B5 (CC2), R6.1
unnamed 44: J2.2 (Data), R10.1; also elsewhere on the board
unnamed 45: J3.2 (Data), R9.1; also elsewhere on the board
unnamed: C10.1, C11.1, R8.2, U1.6 (VS)
unnamed: C1.1, U2.4 (BP)
unnamed: R1.2, U2.3 (EN)
unnamed: C3.1, U3.4 (BP)
unnamed: R2.2, U3.3 (EN)
unnamed: C9.1, R7.1, U4.3 (Vs)
unnamed: C5.1, C6.2, R3.1, SW2.2, U5.3 (EN)
unnamed: SW3.2, U5.27 (IO0)
RX: U5.36 (RXD0); also elsewhere on the board
TCK: U5.32 (IO39)
TDI: U5.34 (IO41)
TDO: U5.33 (IO40)
TMS: U5.35 (IO42)
TX: U5.37 (TXD0); also elsewhere on the board

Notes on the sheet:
Power Management
Microprocessor
Sensors
LEDs
ESC

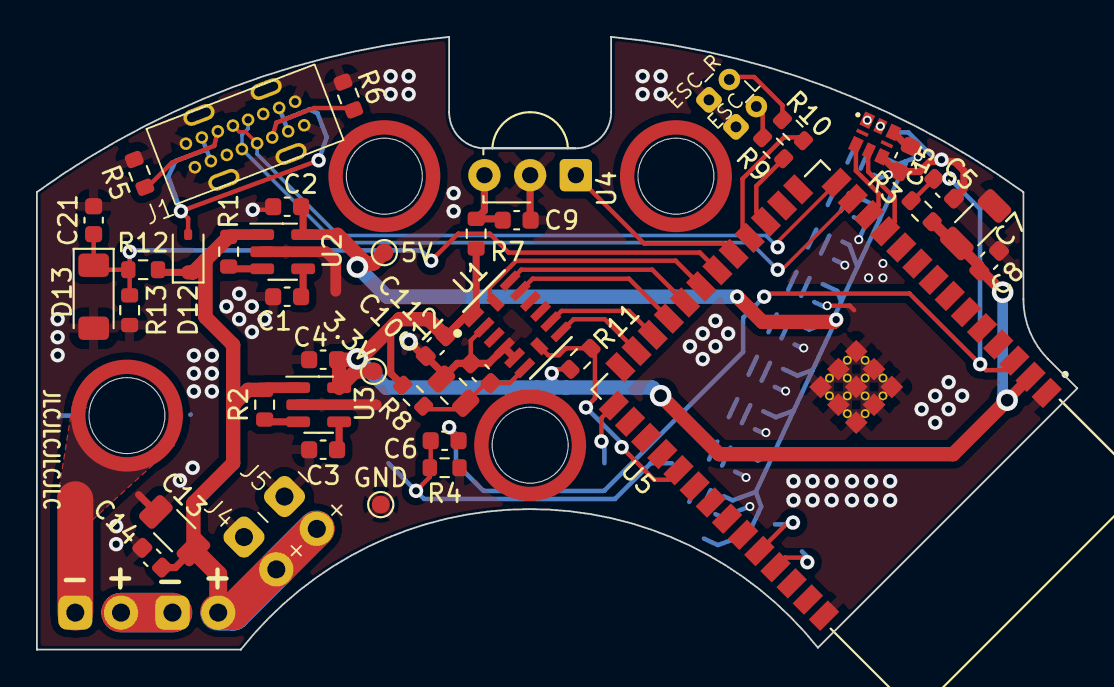
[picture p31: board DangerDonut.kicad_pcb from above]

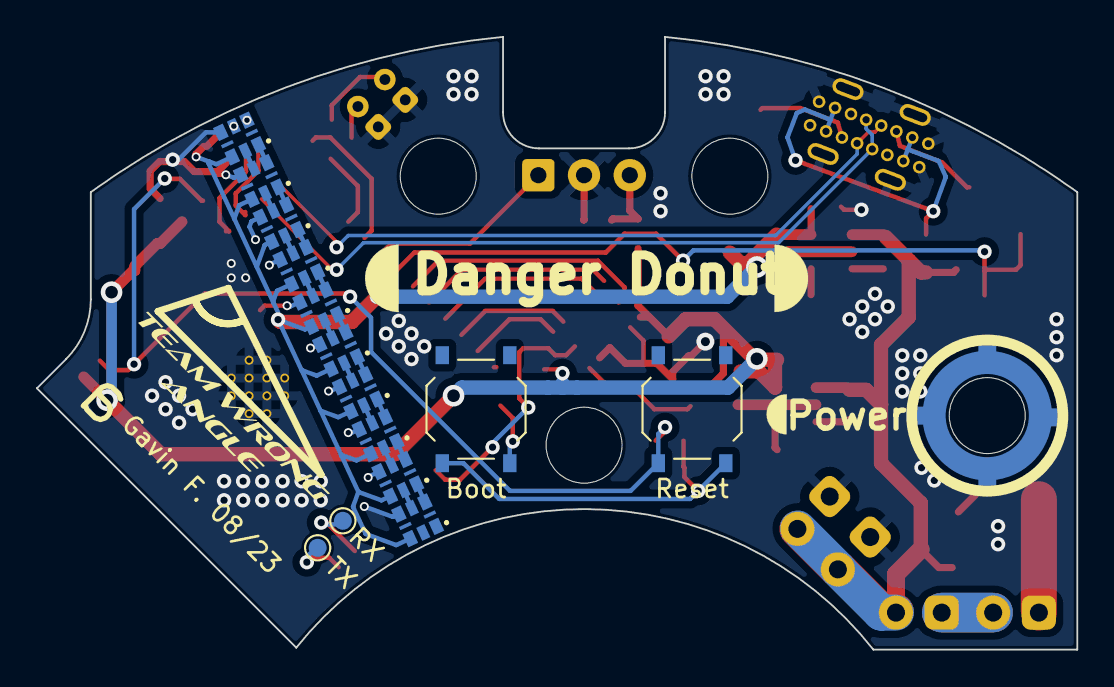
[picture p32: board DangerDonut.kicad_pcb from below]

Board: 2 copper layers, 57.8 x 34.0 mm, 65 parts (14 on the bottom side), 56 nets.

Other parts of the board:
3.3V, 5V: TestPoint_Pad_D1.0mm
ESC_L: ESC_XSD7A_Data
ESC_R: ESC_XSD7A_Data
GND: TestPoint_Pad_D1.0mm
RX: TestPoint_Pad_D1.0mm
TX: TestPoint_Pad_D1.0mm

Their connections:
+3V3: 3.3V.1; also elsewhere on the board
+5V: 5V.1; also elsewhere on the board
GND: ESC_L.1 (GND), ESC_R.1 (GND), GND.1; also elsewhere on the board
unnamed 44: ESC_R.2 (Data); also elsewhere on the board
unnamed 45: ESC_L.2 (Data); also elsewhere on the board
RX: RX.1; also elsewhere on the board
TX: TX.1; also elsewhere on the board

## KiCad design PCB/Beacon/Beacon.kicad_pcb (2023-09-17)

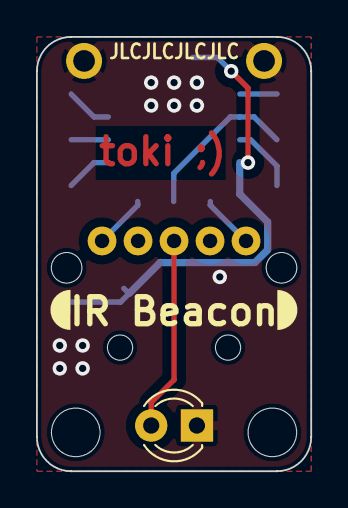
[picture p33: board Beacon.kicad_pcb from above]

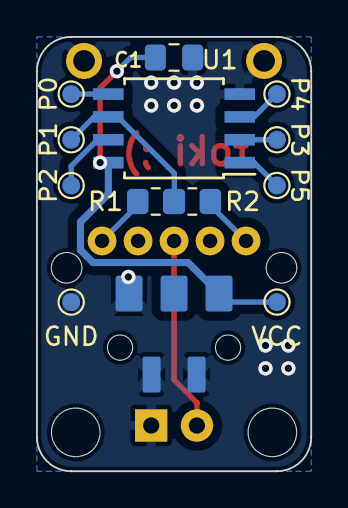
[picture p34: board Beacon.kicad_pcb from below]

Board: 2 copper layers, 15.2 x 24.1 mm, 15 parts (13 on the bottom side), 11 nets.

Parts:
BT1: Battery; 3Pin 2.5MM Spring Contact
C1: 1 uF; C_0805_2012Metric_Pad1.18x1.45mm_HandSolder
D1: LED; LED_D3.0mm_Clear
GND: TestPoint; TestPoint_Pad_D1.0mm
P0, P1, P2, P3, P4, P5: TestPoint; TestPoint_Pad_D1.0mm
R1, R2: 47; R_0805_2012Metric_Pad1.20x1.40mm_HandSolder
RV1: R_Potentiometer; Potentiometer_Piher_PC-16_Single_Vertical
U1: ATtiny85-20S; SOIC-8W_5.3x5.3mm_P1.27mm
VCC: TestPoint; TestPoint_Pad_D1.0mm

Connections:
GND: BT1.2 (-), BT1.4, C1.2, D1.1 (K), GND.1, RV1.GND, U1.4 (GND)
unnamed: D1.2 (A), RV1.2
unnamed: R1.2, RV1.1
unnamed: R2.2, RV1.3
unnamed: P0.1, U1.5 (AREF/PB0)
unnamed: P1.1, R1.1, R2.1, U1.6 (PB1)
unnamed: P2.1, U1.7 (PB2)
unnamed: P3.1, U1.2 (XTAL1/PB3)
unnamed: P4.1, U1.3 (XTAL2/PB4)
unnamed: P5.1, U1.1 (~RESET/PB5)
VCC: BT1.1 (+), C1.1, U1.8 (VCC), VCC.1

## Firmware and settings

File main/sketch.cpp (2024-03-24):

#include "sdkconfig.h"
#ifndef CONFIG_BLUEPAD32_PLATFORM_ARDUINO
#error "Must only be compiled when using Bluepad32 Arduino platform"
#endif  // !CONFIG_BLUEPAD32_PLATFORM_ARDUINO

#include <Arduino.h>
#include <Bluepad32.h>
#include <DShotRMT.h>
#include <driver/timer.h>
#include <HD107S.h>
#include <ADXL375.h>
#include <uni_log.h>
#include <POVDisplay.h>
#include <Preferences.h>
#include <driver/adc.h>
#include <QuickPID.h>
#include <bt_log.h>

#include "orientator.h"

#define LED_COUNT 11U
#define LED_DATA_PIN GPIO_NUM_8
#define LED_CLOCK_PIN GPIO_NUM_18
#define LED_STRIP_RMT_INTR_NUM 11U
#define LED_CLOCK_SPEED 32000000
#define RMT_CHANNEL	RMT_CHANNEL_0

#define LEFT_DSHOT_RMT_CHANNEL RMT_CHANNEL_1
#define LEFT_DSHOT_GPIO GPIO_NUM_9
#define RIGHT_DSHOT_RMT_CHANNEL RMT_CHANNEL_2
#define RIGHT_DSHOT_GPIO GPIO_NUM_10 

#define BATTERY_SENSE GPIO_NUM_12

#define IR_PIN GPIO_NUM_11

#define ADXL_MISO_PIN GPIO_NUM_21
#define ADXL_MOSI_PIN GPIO_NUM_14
#define ADXL_CLOCK_PIN GPIO_NUM_13
#define ADXL_CS_PIN GPIO_NUM_38

#define CONTROLLER_RESPONSE_TIMEOUT 3000000U
#define STICK_DEAD_ZONE 0.1
#define SPIN_THRESHOLD 0.02//13
#define DRIVE_SENSITIVITY 0.1
#define TURN_SENSITIVITY 0.015
#define MELTY_SENSITIVITY 0.25
#define MELTY_TURN_SENSITIVITY 6
#define MAX_ACCELERATION 150
#define JERK_COMPENSATION 400

#define NUM_DECORATIONS 4

GamepadPtr myGamepad;
DShotRMT esc_l, esc_r;
bool buttons[9] = {false, false, false, false, false, false, false, false, false}; // B, <-, ->, ^, v, lb, rb, home, y
bool controller_idle = false;
int spinDirection = 1; // 1: clockwise, -1: withershin
double spin_power = 0;
double offset[2] = {-0.075, 0.15};
esp_timer_create_args_t create_timer;
esp_timer_handle_t test_timer;

double velocity_data[1000];
double velocity_e_data[1000];
double angle_data[1000];
double angle_e_data[1000];
double accel_data[1001];
int readCounter = 0;
int cooldown = 0;
int8_t decor = 0;
float animation = 0;
float disconnectedLEDPos = 0;
int64_t loopStart = 0;
Preferences preferences;
ADXL375 ADXL;
orientator sensor;
HD107S LED;
POVDisplay display;
double targetSpeed = 0;
int flipped = 1;
float pidInput, pidOutput, pidSetPoint;
float Kp = 0.004, Ki = 0.005, Kd = 0.0001; 
//QuickPID pid(&pidInput, &pidOutput, &pidSetPoint);

float getBattVoltage() {
    int voltageReading = 0;
    adc2_get_raw(ADC2_CHANNEL_1, ADC_WIDTH_12Bit, &voltageReading);
    return (float)voltageReading * 1.90 / 4095 * 4.4;
}

// This callback gets called any time a new gamepad is connected.
void onConnectedGamepad(GamepadPtr gp) {
    bool foundEmptySlot = false;
    if (myGamepad == nullptr) {
        Console.printf("CALLBACK: Gamepad is connected\n");

        display.clearStrip();
        for (int i = 0; i < 11; i++)
            display.setStripPixel(i, 0xff00ff00);
        display.makeLEDStrip();

        GamepadProperties properties = gp->getProperties();
        Console.printf("Gamepad model: %s, VID=0x%04x, PID=0x%04x\n", gp->getModelName(), properties.vendor_id,
                        properties.product_id);
        myGamepad = gp;
        foundEmptySlot = true;
    }
    if (!foundEmptySlot) {
        Console.println("CALLBACK: Gamepad connected, but could not find empty slot");
    }
}

void onDisconnectedGamepad(GamepadPtr gp) {
    bool foundGamepad = false;

    if (myGamepad == gp) {
        Console.printf("CALLBACK: Gamepad is disconnected\n");
        //LED1.set_pixel(0, 5, 0, 10);
        //LED1.show();
        myGamepad = nullptr;
        foundGamepad = true;
    }

    if (!foundGamepad) {
        Console.println("CALLBACK: Gamepad disconnected, but not found in myGamepads");
    }
}

void setMotorPower(float left_power, float right_power) {
    //Console.printf("Motor Power: left: %02f, right: %02f\n", left_power, right_power);
    if (left_power < 0) {
        esc_l.sendThrottle(-left_power*999 + 48);
    } else {
        esc_l.sendThrottle(left_power*999 + 1048);
    }
    if (right_power < 0) {
        esc_r.sendThrottle(-right_power*999 + 48);
    } else {
        esc_r.sendThrottle(right_power*999 + 1048);
    }
}

void zeroHeadingCallback() {
    double period = sensor.getPeriod();
    if (period < 10 || period >= 500) return;
    int RPM = 60000/period; // min((int)round(sensor.getVelocity()/ACCEL_POS_SPREAD), NUM_ACCEL_POS-1);
    display.clear();
    uint32_t color = 0xFF2255FF;
    if (getBattVoltage() < 6.5) color = 0xFFFF2222;
    switch (decor) {
    case 0: // RPM
        if (RPM >= 1000) display.drawDigit(28, 0, RPM/1000 % 10, color);
        if (RPM >= 100) display.drawDigit(35, 0, RPM/100 % 10, color);
        if (RPM >= 10) display.drawDigit(43, 0, RPM/10 % 10, color);
        display.drawDigit(50, 0, RPM % 10, color);
        break;
    case 1: // donut
        display.drawSprite(0,0,11);
        break;
    case 2: // nyan cat
        if (animation < 0) animation = 83;
        if (((int)(animation + 2) % 12) < 4) display.drawSprite(20, 4, 17-((int)(animation + 2) % 12));
        if (((int)(animation + 8) % 12) < 4) display.drawSprite(64, 0, 17-((int)(animation + 8) % 12));
        if (((int)(animation + 4) % 12) < 4) display.drawSprite(47, 4, 17-((int)(animation + 4) % 12));
        if (((int)(animation + 6) % 12) < 4) display.drawSprite(0, 2, 17-((int)(animation + 6) % 12));
        if(((int)animation % 8) >= 4) {
            display.drawSprite(animation,0,12);
        } else {
            display.drawSprite(animation,0,13);
        }
        animation -= period/84;
        break;
    case 3: // pride flags
        if (animation >= 9) animation = 0;
        for (int i = 0; i < 84; i++)
            display.drawSprite(i, 0, 18 + (int)animation);
        animation += period/4000;
        break;
    default: // debug
        display.drawSprite(40,0,10);
        break;
    }

    for (int i = 2; i < 84; i++) {
        if (!sensor.getIRData(i*period/84)) {
            display.setPixel(i, 9, 0xff00ff00);
            display.setPixel(i, 10, 0xff00ff00);
        }
    }
    display.setPixel(0,10, 0xff0000ff);
    display.setPixel(1,10, 0xff0000ff);
    display.setPixel(0,9, 0xff0000ff);
    display.setPixel(1,9, 0xff0000ff);
    display.setPixel(0,8, 0xff0000ff);
    display.setPixel(1,8, 0xff0000ff);
    display.makeFrame(period, spinDirection);
}

void onStopCallback() {
    display.clearStrip();
    for (int i = 0; i < 11; i++)
        display.setStripPixel(i, 0xff00ff00);
    display.makeLEDStrip();
}

float velocityFollow(float current, float target, float deltaTime) {
    float step = deltaTime*MAX_ACCELERATION;
    if (abs(target - current) >= step) {
        return current + copysignf(step, target-current);
    }
    return target;
}

// Arduino setup function. Runs in CPU 1
void setup() {

    preferences.begin("config");
    // preferences.putInt("XOffset", -9);
    // preferences.putInt("YOffset", -6);
    // preferences.putInt("ZOffset", 15);

    Console.println("Offsets:");
    Console.printf("X: %d\n", preferences.getInt("XOffset"));
    Console.printf("Y: %d\n", preferences.getInt("YOffset"));
    Console.printf("Z: %d\n", preferences.getInt("ZOffset"));

    hd107s_config_t LED_config;
    LED_config.dataPin = LED_DATA_PIN;
    LED_config.clockPin = LED_CLOCK_PIN;
    LED_config.numLEDs = LED_COUNT;
    LED_config.clockSpeed = LED_CLOCK_SPEED;
    //LED.setup(LED_config);

    display = POVDisplay(LED_config);
    display.setBrightness(64);

    adxl375_spi_config_t adxl_config;
    adxl_config.clockPin = ADXL_CLOCK_PIN;
    adxl_config.misoPin = ADXL_MISO_PIN;
    adxl_config.mosiPin = ADXL_MOSI_PIN;
    adxl_config.csPin = ADXL_CS_PIN;
    adxl_config.xOffset = preferences.getInt("XOffset", 0);
    adxl_config.yOffset = preferences.getInt("YOffset", 0);
    adxl_config.zOffset = preferences.getInt("ZOffset", 0);

    Console.println("testing ADXL");
    if (ADXL.setup(adxl_config)) {
        Console.println("adxl375 sensor found");
    } else {
        Console.println("error with adxl375");
    }

    Console.printf("Firmware: %s\n", BP32.firmwareVersion());
    const uint8_t* addr = BP32.localBdAddress();
    Console.printf("BD Addr: %2X:%2X:%2X:%2X:%2X:%2X\n", addr[0], addr[1], addr[2], addr[3], addr[4], addr[5]);

    // Setup the Bluepad32 callbacks
    BP32.setup(&onConnectedGamepad, &onDisconnectedGamepad);

    BP32.forgetBluetoothKeys();
    esc_l.install(LEFT_DSHOT_GPIO, LEFT_DSHOT_RMT_CHANNEL);
    esc_r.install(RIGHT_DSHOT_GPIO, RIGHT_DSHOT_RMT_CHANNEL);

    sensor.setup(IR_PIN, ADXL);
    sensor.setZeroCrossCallback(&zeroHeadingCallback);
    sensor.setOnStopCallback(&onStopCallback);

    char readLocation[10] = "AccelPos ";
    Console.println("Accel config:");
    for (int i = 0; i < NUM_ACCEL_POS; i++) {
        readLocation[8] = i+'0';
        sensor.setAccelPos(preferences.getDouble(readLocation, 0.03), i);
        Console.printf("%s: %f\n",readLocation , preferences.getDouble(readLocation));
    }

    adc2_config_channel_atten(ADC2_CHANNEL_1, ADC_ATTEN_6db);

    //pidSetPoint = 0;
    //pid.SetTunings(Kp, Ki, Kd);
    //pid.SetMode(pid.Control::automatic);
    //pid.SetOutputLimits(0,1);
    //pid.SetSampleTimeUs(4000);
}

// Arduino loop function. Runs in CPU 1
void loop() {

    double deltaTime = ((double)(esp_timer_get_time() - loopStart))/1000000;
    loopStart = esp_timer_get_time();
    BP32.update();

    if (myGamepad && myGamepad->isConnected()) {

        controller_idle = esp_timer_get_time() - myGamepad->getUpdateTime() > CONTROLLER_RESPONSE_TIMEOUT;

        double logVelocity = 0;
        double logAngle = 0;
        double logAngle_e = 0;
        double logVelocity_e = 0;
        double logAccel_e = 0;
        sensor.update(logAngle, logVelocity, logAngle_e, logVelocity_e, logAccel_e);
        //ESP_LOGI("imu", "x: %f, y: %f, z: %f", -sensor.getXAccel()/LSB2G_MULTIPLIER, sensor.getYAccel()/LSB2G_MULTIPLIER, -sensor.getZAccel()/LSB2G_MULTIPLIER);

        //Console.printf("%03f\n", sensor.getZSign());
        //pidInput = sensor.getVelocity();
        double previousPower = pidOutput;
        //pid.Compute();
        if (sensor.getVelocity() < 75)
            flipped = sensor.getZSign();

        if (!controller_idle) {

            float left_power = 0;
            float right_power = 0;
            float y = -((float)myGamepad->axisY())/512;
            float x = ((float)myGamepad->axisX())/512;
            float r = ((float)myGamepad->axisRX())/512;

            //targetSpeed = velocityFollow(targetSpeed, VELOCITY_MAX*(float)(myGamepad->throttle() - myGamepad->brake())/1024, deltaTime);
            //pidSetPoint = abs(targetSpeed);

            pidOutput = (float)(myGamepad->throttle() - myGamepad->brake())/1024;
            spinDirection = flipped*copysignf(1.0, pidOutput);
            pidOutput = copysignf(pidOutput, spinDirection);

            if (abs(pidOutput) < SPIN_THRESHOLD) { // run in tank drive if not spinning
                if (abs(y) > STICK_DEAD_ZONE) {
                    left_power += y * DRIVE_SENSITIVITY;
                    right_power -= y * DRIVE_SENSITIVITY;
                }
                if (abs(r) > STICK_DEAD_ZONE) {
                    left_power += r * TURN_SENSITIVITY;
                    right_power += r * TURN_SENSITIVITY;
                }
            } else { // melty mode
                sensor.adjustAccel((pidOutput - previousPower)*JERK_COMPENSATION);
                //ESP_LOGI("pid", "setPoint: %f, input: %f, output: %f", pidSetPoint, pidInput, pidOutput);
                float hypot = hypotf(x,y);
                if (hypot < STICK_DEAD_ZONE) hypot = 0;
                float theta = atan2f(y,x) + offset[(spinDirection+1)/2]*2*PI;
                if (flipped < 0) theta += PI; // reverse controls when flipped
                const float meltyPower = MELTY_SENSITIVITY*hypot*sin(spinDirection*sensor.getAngle() + theta);
                left_power = pidOutput + meltyPower;
                right_power = pidOutput - meltyPower;

                if (abs(r) > STICK_DEAD_ZONE) {
                    double turnAmount = -MELTY_TURN_SENSITIVITY*r*deltaTime;
                    sensor.adjustAngle(spinDirection*turnAmount);
                }
            }

            if (abs(left_power) > 1 || abs(right_power) > 1) {
                float max_power = max(abs(left_power), abs(right_power));
                left_power /= max_power;
                right_power /= max_power;
            }

            if (myGamepad->x()) { // self right using wheel's inertia
                left_power = 1;
                right_power = -1;
            }

            if (myGamepad->up()) {
                double angle = atan2(sensor.getYAccel(), sensor.getXAccel());
                if (angle < -PI/4 || angle > 3*PI/4) {
                    left_power = -1;
                    right_power = 1;
                } else {
                    left_power = 1;
                    right_power = -1;
                }
            }

            if (myGamepad->down()) {
                double angle = atan2(sensor.getYAccel(), sensor.getXAccel());
                if (angle < -PI/4 || angle > 3*PI/4) {
                    left_power = 1;
                    right_power = -1;
                } else {
                    left_power = -1;
                    right_power = 1;
                }
            }

            setMotorPower(left_power, right_power);

            if (myGamepad->b()) {
                if (!buttons[0]) {
                    buttons[0] = true;
                    for (int i = 0; i < 1000; i++) {
                        Console.printf("%lf	%lf	%lf	%lf	%lf 	\n", angle_data[i], velocity_data[i], angle_e_data[i], velocity_e_data[i], accel_data[i]);
                    }
                    Console.print("\n");
                }
            } else {
                buttons[0] = false;
            }

            if (myGamepad->a()) {
                if (readCounter >= 1000) readCounter = 0;
                if (/*readCounter < 1000 && */logVelocity > 0.1) {
                    velocity_data[readCounter] = logVelocity;
                    velocity_e_data[readCounter] = logVelocity_e;
                    angle_data[readCounter] = logAngle;
                    angle_e_data[readCounter] = logAngle_e;
                    accel_data[readCounter] = logAccel_e;
                    readCounter++;
                }
            }

            if (myGamepad->l1()) {
                if (!buttons[5]) {
                    buttons[5] = true;
                    animation = 0;
                    decor --;
                    if (decor < 0)
                        decor = NUM_DECORATIONS-1;
                }
            } else {
                buttons[5] = false;
            }

            if (myGamepad->r1()) {
                if (!buttons[6]) {
                    buttons[6] = true;
                    animation = 0;
                    decor ++;
                    if (decor >= NUM_DECORATIONS)
                        decor = 0;
                }
            } else {
                buttons[6] = false;
            }

            if (myGamepad->left()) {
                if (!buttons[1]) {
                    buttons[1] = true;
                    sensor.setAccelPos(sensor.getAccelPos() - 0.00005);
                    Console.printf("AccelPos: %f\n", sensor.getAccelPos());
                }
            } else {
                buttons[1] = false;
            }

            if (myGamepad->right()) {
                if (!buttons[2]) {
                    buttons[2] = true;
                    sensor.setAccelPos(sensor.getAccelPos() + 0.00005);
                    Console.printf("AccelPos: %f\n", sensor.getAccelPos());
                }
            } else {
                buttons[2] = false;
            }

            if (myGamepad->miscHome()) {
                if (!buttons[7]) {
                    buttons[7] = true;
                    setMotorPower(0,0);
                    myGamepad->disconnect();
                }
            } else {
                buttons[7] = false;
            }

            if (myGamepad->y()) {
                if (!buttons[8]) {
                    buttons[8] = true;
                    char saveLocation[10] = "AccelPos ";
                    for (int i = 0; i < NUM_ACCEL_POS; i ++) {
                        saveLocation[8] = i+'0';
                        preferences.putDouble(saveLocation, sensor.getAccelPos(i));
                        Console.print(saveLocation);
                        Console.printf(": %f\n", sensor.getAccelPos(i));
                    }
                }
            } else {
                buttons[8] = false;
            }
        } else {
            //pidSetPoint = velocityFollow(pidSetPoint, 0, deltaTime);
            //pid.SetOutputSum(0);
            setMotorPower(0,0);
        }
    } else {
        setMotorPower(0,0);
        sensor.stopZeroCrossCallback();
        display.clearStrip();
        display.setStripPixel(floor(abs(disconnectedLEDPos-9)), 0xffff0000);
        display.makeLEDStrip();
        disconnectedLEDPos += 0.03;
        if (disconnectedLEDPos >= 19)
            disconnectedLEDPos = 0;
    }
    vTaskDelay(1);
}

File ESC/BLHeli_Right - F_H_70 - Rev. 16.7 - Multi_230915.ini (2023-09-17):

[ESC0]
Eep_Name=Right
Eep_ESC_Layout=F_H_70
Eep_ESC_MCU=#BLHELI$EFM8B21#
Eep_ESC_Mode=2
Eep_FW_Main_Revision=16
Eep_FW_Sub_Revision=7
Eep_Layout_Revision=33
Eep_Pgm_Startup_Pwr=9
Eep_Pgm_Direction=3
Eep_Enable_TX_Setup=1
Eep_Pgm_Comm_Timing=3
Eep_Pgm_Ppm_Min_Throttle=0
Eep_Pgm_Ppm_Max_Throttle=250
Eep_Pgm_Beep_Strength=40
Eep_Pgm_Beacon_Strength=80
Eep_Pgm_Beacon_Delay=4
Eep_Pgm_Demag_Comp=2
Eep_Pgm_Ppm_Center_Throttle=125
Eep_Pgm_Temp_Prot_Enable=7
Eep_Pgm_Enable_Power_Prot=1
Eep_Pgm_Brake_On_Stop=0
Eep_Pgm_LED_Control=0

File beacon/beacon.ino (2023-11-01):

void setup() {
  // using timer 1
  DDRB = 1<<DDB1; // PB1 as output
  TCCR1 = 1<<CTC1 | 1<<COM1A0 | 1<<CS11; // CTC mode, toggle OC1A (PB1), divide by 2 prescaler
  OCR1C = 226; // 38 kHz   32,000,000 / (2*2*(1+210))


  // using timer 0
  // DDRB = 1<<DDB0; // PB0 as output
  // TCCR0A = 1<<COM0A0 | 1<<WGM01; // toggle OC0A, CTC mode
  // TCCR0B = 1<<CS00; // no prescaling
  // OCR0A = 52; // 37.7 kHz   4,000,000 / (2*1*(1+52))
}

void loop() {

}

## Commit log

2023-08-15 feat: convolution, melty control
    [orientator.h, sketch.cpp]
2023-08-16 "fixed" apa102, started PCB
    [DangerCookie.kicad_pcb, DangerCookie.kicad_sch]
2023-08-21 updated PCB
    [DangerCookie.kicad_pcb, DangerDonut.kicad_pcb, DangerDonut.kicad_sch]
2023-09-17 feat: HD107S LED support
2023-09-17 beacon PCB
    [Beacon.kicad_pcb, Beacon.kicad_sch]
2023-09-17 mainBoard PCB
    [DangerDonut.kicad_pcb, DangerDonut.kicad_sch, ESP32-S3-WROOM-1-N16--3DModel-STEP-269445.STEP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]
2023-09-22 Added Accelerometer
2023-09-22 HD107S LED driver
2023-10-23 feat: POV display, fixed tracking at low speeds
    [POVDisplay.cpp]
2023-11-01 feat: kalman filter for orientation
2023-11-01 removed unused components
    [DangerDonut.kicad_pcb, DangerDonut.kicad_sch]
2023-11-01 feat: 1D LED control, new decorations
2023-11-28 bug fixes, PID controller
    [ADXL375.cpp, POVDisplay.cpp]
2023-12-06 switched to multi-byte read from ADXL
2024-01-03 new decor, fixed zero offsets, self right
    [ADXL375.cpp, ADXL375.h, orientator.h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]
2024-03-24 removed PID
2024-03-24 started bt_log (not working)
    [sketch.cpp]
